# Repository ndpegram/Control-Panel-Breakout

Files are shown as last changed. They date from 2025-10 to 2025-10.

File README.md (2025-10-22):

# Simple Control Panel Breakout

This pcb allows the remote control of a point motor via 4 wires:

 1. +5v
 2. Gnd
 3. LED indicator (high/low)
 4. Pushbutton (active low)

These four wires must share a common ground with the controller. They assume that the point's position is toggled by pressing the pushbutton which is active low. The board takes the signal on the single LED wire and converts it to two LEDs to indicate whether the point is straight or thrown.

The button and LEDs can be mounted directly onto the PCB and the PCB attached to the rear of the panel using the included screw hole. In this case, through-hole (THT) LEDs are recommended. The tactile switch should have a shaft long enough to protrude through the panel fascia. Included is a drilling template (created in FreeCAD) which can be used to drill the button and LED holes. Note that surface-mount (SMD) LEDs could be used by soldering them between the LED pads on the PCB.

Alternatively, the PCB can be mounted elsewhere, and the LEDs and button connected via wires to the appropriate holes on the PCB.

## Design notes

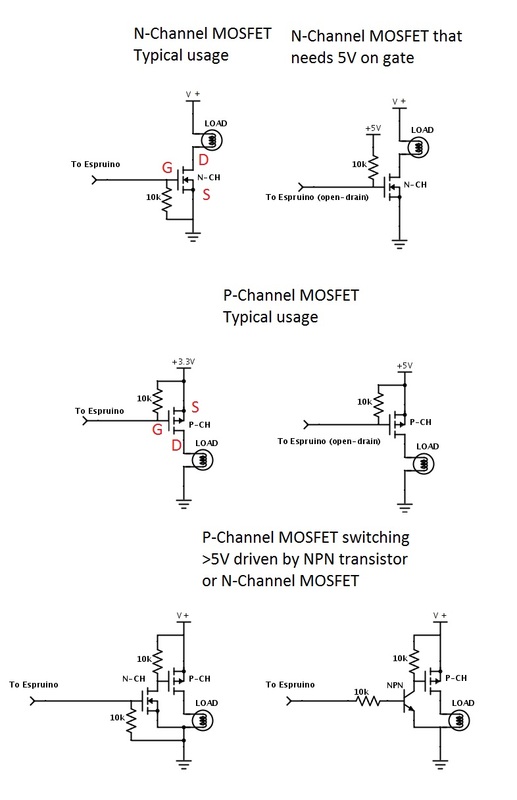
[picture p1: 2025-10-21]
mosfets_mosfetschematic.jpg

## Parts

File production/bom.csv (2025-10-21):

Designator | Footprint | Quantity | Value | LCSC Part #
D1, D2 | LED_D5.0mm | 2 | Red
J1 | JST_XH_B4B-XH-A_1x04_P2.50mm_Vertical | 1 | Conn_01x04_Pin
J2 | JST_XH_B2B-XH-A_1x02_P2.50mm_Vertical | 1 | Conn_01x02_Pin
Q1 | SOT-23_Handsoldering | 1 | AO3400A
Q2 | SOT-23_Handsoldering | 1 | AO3401A
R1 | 0805 | 1 | 1k
R2, R3 | 0805 | 2 | 330R
R4 | 0805 | 1 | 10k
SW1 | SW_PUSH_6mm_H5mm | 1 | SW_Push_Dual

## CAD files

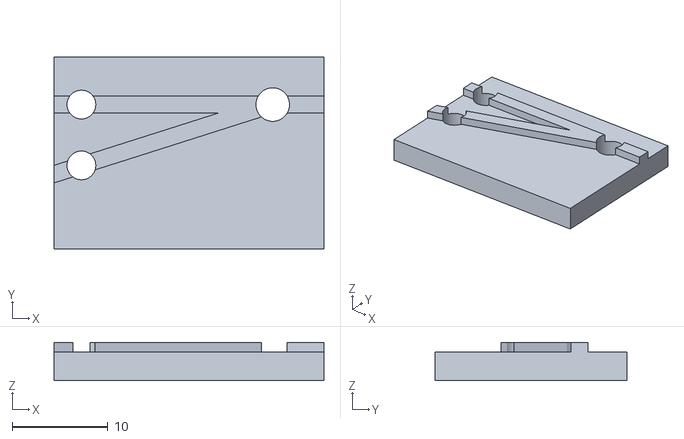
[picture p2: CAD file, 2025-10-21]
Drilling Template/Drilling Template-Body.stl
28.2 x 20.0 x 4.00

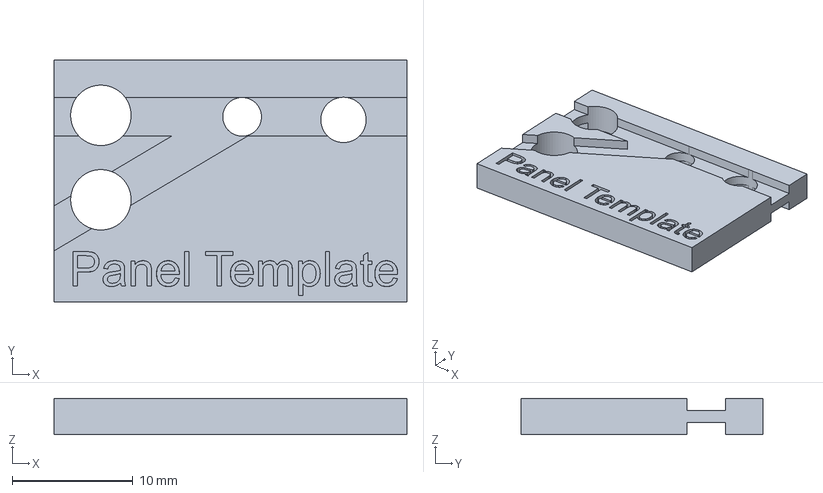
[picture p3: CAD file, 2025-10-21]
Panel Template.FCStd
29.2 x 20.0 x 3.00 mm

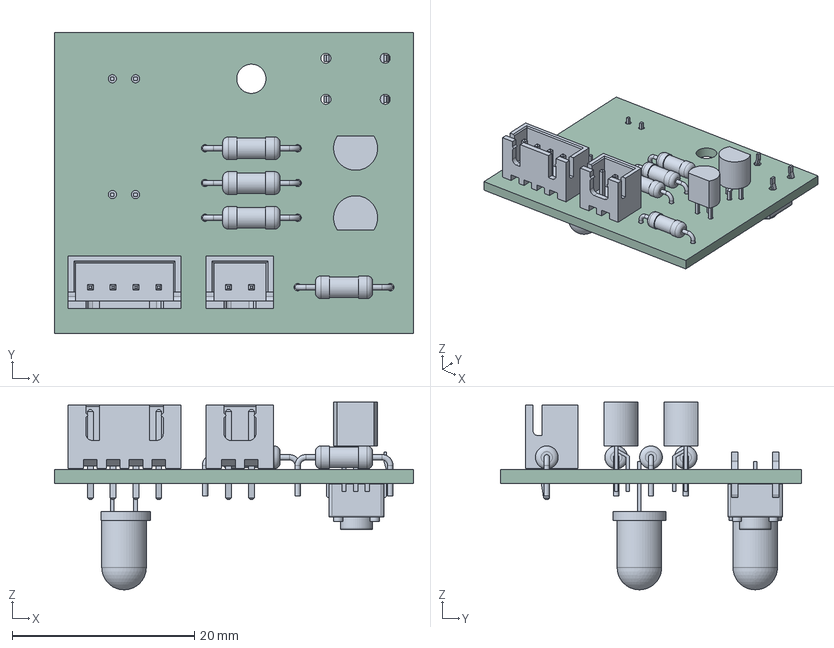
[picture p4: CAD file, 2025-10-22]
THT Board/Control Panel Breakout THT.step
39.4 x 33.0 x 20.6 mm
JST_XH_B4B-XH-A_1x04_P2.50mm_Vertical
R_Axial_DIN0207_L6.3mm_D2.5mm_P10.16mm_Horizontal x 4
TO-92 x 2
JST_XH_B2B-XH-A_1x02_P2.50mm_Vertical
LED_D5.0mm x 2
SW_PUSH_6mm_H5mm
Control Panel Breakout THT_PCB

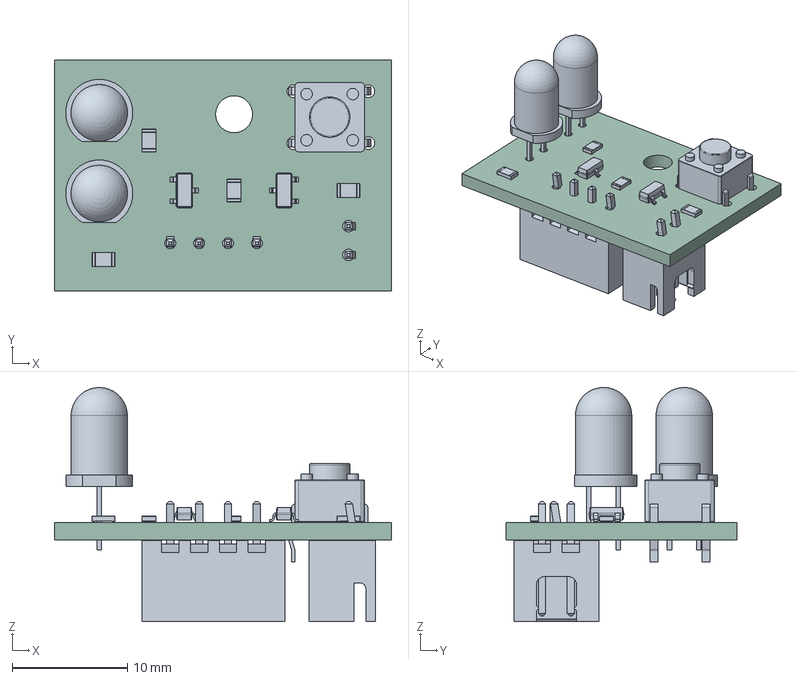
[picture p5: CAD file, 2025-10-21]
Control Panel Breakout.step
29.2 x 20.0 x 20.3 mm
LED_D5.0mm x 2
SOT-23 x 2
R_0805_2012Metric x 4
SW_PUSH_6mm_H5mm
JST_XH_B2B-XH-A_1x02_P2.50mm_Vertical
JST_XH_B4B-XH-A_1x04_P2.50mm_Vertical
Control Panel Breakout_PCB

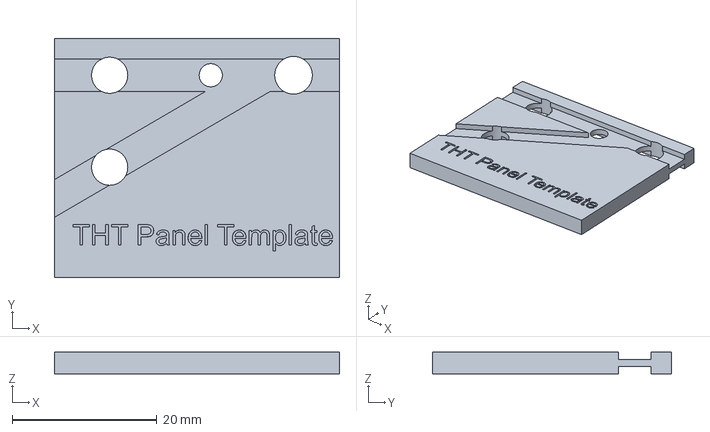
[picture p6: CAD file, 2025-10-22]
THT Board/Panel Template THT.FCStd
39.4 x 33.0 x 3.00 mm

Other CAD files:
Drilling Template/Drilling Template.FCStd
Panel Template.stl

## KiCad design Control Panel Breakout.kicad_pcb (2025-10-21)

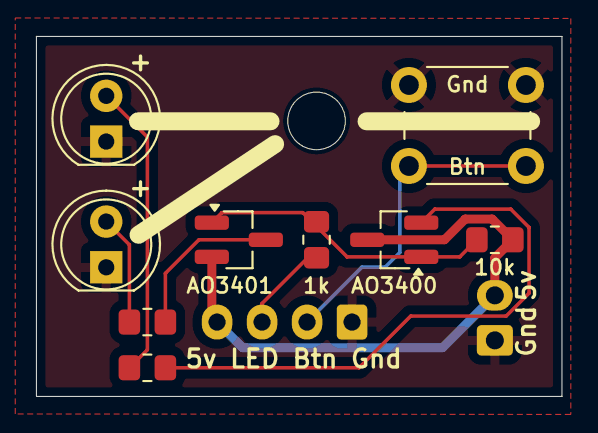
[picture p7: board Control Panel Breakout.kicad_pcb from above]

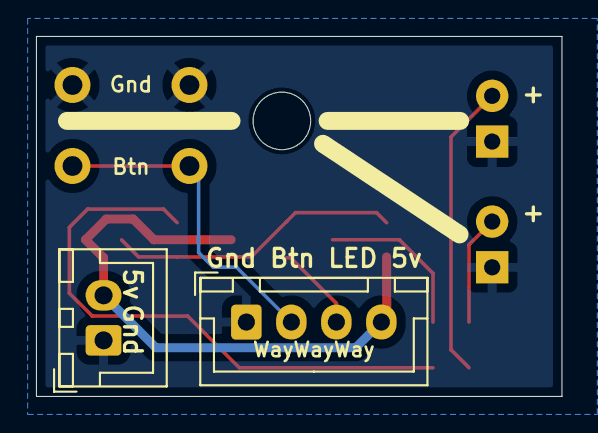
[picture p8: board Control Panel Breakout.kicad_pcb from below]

Board: 2 copper layers, 29.2 x 20.0 mm, 12 parts (2 on the bottom side), 9 nets.

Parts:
D1, D2: Red; LED_D5.0mm
H1: MountingHole; MountingHole_3.2mm_M3
J1: Conn_01x04_Pin; JST_XH_B4B-XH-A_1x04_P2.50mm_Vertical
J2: Conn_01x02_Pin; JST_XH_B2B-XH-A_1x02_P2.50mm_Vertical
Q1: AO3400A; SOT-23_Handsoldering
Q2: AO3401A; SOT-23_Handsoldering
R1: 1k; R_0805_2012Metric_Pad1.20x1.40mm_HandSolder
R2, R3: 330R; R_0805_2012Metric_Pad1.20x1.40mm_HandSolder
R4: 10k; R_0805_2012Metric_Pad1.20x1.40mm_HandSolder
SW1: SW_Push_Dual; SW_PUSH_6mm_H5mm

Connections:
+5V: J1.4, J2.2, Q1.3 (D), Q2.2 (S), R4.2
/Diverging: Q2.3 (D), R3.1
/MimicButton: J1.2, SW1.2
/MimicLED: J1.3, R1.2
/Straight: Q1.2 (S), R2.1
/signal: Q1.1 (G), Q2.1 (G), R1.1, R4.1
GND: D1.1 (K), D2.1 (K), J1.1, J2.1, SW1.1
unnamed: D1.2 (A), R2.2
unnamed: D2.2 (A), R3.2

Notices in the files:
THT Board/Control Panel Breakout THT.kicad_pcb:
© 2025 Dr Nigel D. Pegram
